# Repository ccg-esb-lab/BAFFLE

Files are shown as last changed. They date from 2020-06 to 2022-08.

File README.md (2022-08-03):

# BAFFLE - Bionic Apparatus For Fluorescent Light Estimation

Repository for: <br><br>
**BAFFLE: A 3D printable device for macroscopic quantification of fluorescent bacteria in space and time**<br>
_Carles Tardío Pi, Daniela Reyes-González, Andrea Fernández-Duque, Ayari Fuentes-Hernández, Fernando Santos-Escobar, and Rafael Peña-Miller_.


## Overview

Here you can find the hardware design files, code and materials for assemblying a low cost and open source opto-mechanical device with the aim of acquiring multi-channel time-lapse images of bacterial colonies growing in agar plates.  

This device uses a system of addressable LEDs and fluorescence filters to estimate the spatio-temporal distribution of different fluorescently-tagged sub-populations from time-lapse images obtained using a standard DSLR camera with a macro lens.

## Documentation

Step-by-step assembly instructions can be found [here](http://www.penamiller.com/lab/baffle/).<br>

List of components can be found [here](https://penamiller.com/lab/baffle/XLS/BAFFLEdoc_parts.xlsx).

Data used to produce figures included in the manuscript can be found in [data/](data/). 

ImageJ macros and Matlab scripts used to analyze these images can be found in [macros/](macros/).

## Authors

[@Systems Biology Lab, CCG-UNAM](https://github.com/ccg-esb-lab)

## License

[MIT](https://choosealicense.com/licenses/mit/)

This project is licensed under the MIT License - see the [license.txt](../license.txt) file for details. Hardware is lincesed under the CERN license.

## Aknowledgements

We thank the help and input from past and present members of the Systems and Synthetic Laboratory at CCG-UNAM.

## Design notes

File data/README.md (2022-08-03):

This directory contains raw images and data used to produce the figures in the manuscript "BAFFLE: A 3D printable device for macroscopic quantification of fluorescent bacteria in space and time".

*Figure 2* <br/>
Raw data: [data/Figure_calibration/](../data/Figure_calibration/)

*Figure 3* <br/>
Raw data: [data/Figure_colonies/](../data/Figure_colonies/)

*Figure 4* <br/>
Raw data: [data/Figure_gradient/](../data/Figure_gradient/)

*Figure 5* <br/>
Raw data: [data/Figure_timelapse/](../data/Figure_timelapse/)

*Figure 6* <br/>
Raw data: [data/Figure_expansion/](../data/Figure_expansion/)

## License

[MIT](https://choosealicense.com/licenses/mit/)

This project is licensed under the MIT License - see the [license.txt](../license.txt) file for details. Hardware is lincesed under the CERN license.

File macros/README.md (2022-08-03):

This directory contains [ImageJ](https://imagej.net/software/fiji/) macros used to process images used in the manuscript "BAFFLE: A 3D printable device for macroscopic quantification of fluorescent bacteria in space and time".

*Figure 2* <br/>
Macro: _Figure_calibration.ijm_ <br/>
Raw data: [data/Figure_calibration/](../data/Figure_calibration/)

*Figure 3* <br/>
Macro: _Figure_colonies.ijm_ <br/>
Raw data: [data/Figure_colonies/](../data/Figure_colonies/)

*Figure 4* <br/>
Raw data: [data/Figure_gradient/](../data/Figure_gradient/)

*Figure 5* <br/>
Macro: _Figure_timelapse.ijm_ <br/>
Raw data: [data/Figure_timelapse/](../data/Figure_timelapse/)

*Figure 6* <br/>
Macro: _Figure_expansion.ijm_ <br/>
Raw data: [data/Figure_expansion/](../data/Figure_expansion/)

Plots were generated in Matlab using the following script _runMe.m_

## License

[MIT](https://choosealicense.com/licenses/mit/)

This project is licensed under the MIT License - see the [license.txt](../license.txt) file for details. Hardware is lincesed under the CERN license.

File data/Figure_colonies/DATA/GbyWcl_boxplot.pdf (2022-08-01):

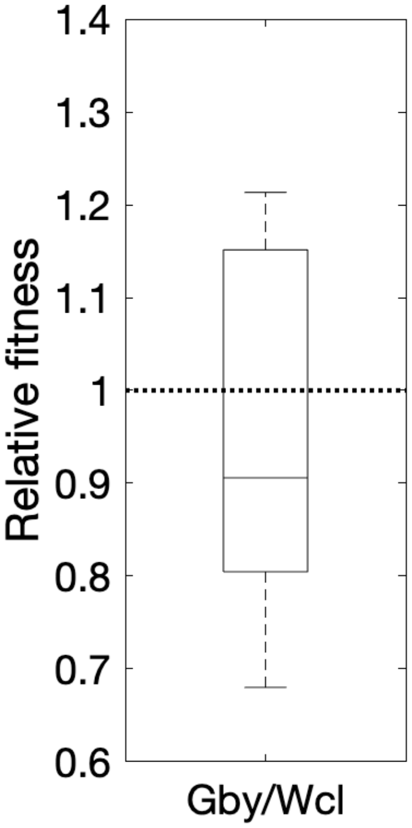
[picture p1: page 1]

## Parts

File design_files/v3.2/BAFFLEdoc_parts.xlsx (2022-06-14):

 | ELECTRONICS & PARTS LIST | REF | PRICE (APPROX. USD)
1 | PhidgetInterfaceKit 8/8/88 | https://www.phidgets.com/?prodid=1021 | 80$
2 | PhidgetStepper Bipolar HC | https://www.phidgets.com/?tier=3&catid=23&pcid=20&prodid=1029 | 180$
1 | Arduino Mega 2560 Rev3 | https://store.arduino.cc/products/arduino-mega-2560-rev3 | 33$
1 | Grove - Mega Shield v1.2 | https://www.seeedstudio.com/Grove-Mega-Shield-v1-2.html | 11$
1 | Grove - Temperature&Humidity Sensor | https://wiki.seeedstudio.com/Grove-TemptureAndHumidity_Sensor-High-Accuracy_AndMini-v1.0/ | 13$
2 | NEMA 17 Stepper Motor | https://openbuildspartstore.com/nema-17-stepper-motor/ | 36$
4 | SinkPAD-II 23mm Quad LED Modules | https://www.luxeonstar.com/sinkpad-23mm-quad-led-modules | 100$
4 | LED Heat Sink | https://www.luxeonstar.com/50mm-round-4.9-degree-cw-alpha-heat-sink | 33$
1 | BuckPuck DC LED Driver | https://www.luxeonstar.com/1000ma-externally-dimmable-buckpuck-dc-driver-leads | 11$
1 | 60leds/m 12v ws2812b led strip | https://www.alibaba.com/product-detail/12v-Led-Led-Waterproof-Led-Strip_62439538213.html?s=p | 25$
4 | Thorlabs Fluorescence Imaging Filters Kit | https://www.thorlabs.com/newgrouppage9.cfm?objectgroup_id=2990 | 1028$
3 | 5v Relay Module 1 Channel 12vdc | https://articulo.mercadolibre.com.mx/MLM-657067999-modulo-relevador-relay-1-canal-12v-_JM?matt_tool=54128181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 | 3$
5 | N-Channel MOSFET 60V 30A | https://www.sparkfun.com/products/10213 | 5$
1 | TEC1-12706 Peltier Kit | https://www.amazon.com.mx/Lsgoodcare-Semiconductor-Thermoel%C3%A9ctrico-refrigeraci%C3%B3n-TEC1-12706/dp/B09GFKWP49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 | 23$
1 | 12V 30A DC Regulated Power Supply | https://www.amazon.com.mx/BMOUO-Universal-Regulated-Switching-Computer/dp/B01EWG6YT8?adgrpid=101194324775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 | 40$
2 | Limit Switch | https://articulo.mercadolibre.com.mx/MLM-642073992-limit-switch-interruptor-final-carrera-kw11-3z-arduino-pic-_JM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 | 4$
4 | Thermal Adhesive Tape for 23 mm Quad LED Assemblies | https://www.luxeonstar.com/pre-cut-thermal-adhesive-tape-for-quad-leds-12pcs | 8$
1 | 2GT Timing Belt Pulley Kits GT2 Timing Belt Closed-Loop 200mm | https://www.amazon.com/dp/B01M2DL73S/ref=cm_sw_r_cp_api_i_Z3ENCbVTZ6J9D | 11$
4 | OpenBuilds V-Slot 20x20x200mm | https://openbuildspartstore.com/v-slot-20x20-linear-rail/ | 11$
6 | OpenBuilds V-Slot 20x20x250mm | https://openbuildspartstore.com/v-slot-20x20-linear-rail/ | 16$
4 | OpenBuilds V-Slot 20x20x500mm | https://openbuildspartstore.com/v-slot-20x20-linear-rail/ | 22$
5 | OpenBuilds V-Slot 20x40x500mm | https://openbuildspartstore.com/v-slot-20x40-linear-rail/ | 35$
2 | OpenBuilds V-Slot 20x40x250mm | https://openbuildspartstore.com/v-slot-20x40-linear-rail/ | 7$
1 | OpenBuilds V-Slot 40x40x500mm | https://openbuildspartstore.com/v-slot-40x40-linear-rail/ | 14$
16 | 90 Degree Joining Plate | https://openbuildspartstore.com/90-degree-joining-plate/ | 80$
24 | Inside Hidden Corner Bracket | https://openbuildspartstore.com/inside-hidden-corner-bracket/ | 47.76$
1 | OpenBuilds C-Beam Linear Rail | https://openbuildspartstore.com/c-beam-linear-rail/ | 18$
100 | Low Profile M5 Screw | https://openbuildspartstore.com/low-profile-screws-m5-10-pack/ | 9$
30 | Tee Nuts - M5 | https://openbuildspartstore.com/tee-nuts-m5-10-pack/ | 9$
12 | Drop In Tee Nuts | https://openbuildspartstore.com/drop-in-tee-nuts/ | 12$
2 | Motor Mount Plate - NEMA 17 Stepper Motor | https://openbuildspartstore.com/motor-mount-plate-nema-17-stepper-motor/ | 14$
2 | 1/4" x 8mm Flexible Coupling | https://openbuildspartstore.com/1-4-x-8mm-flexible-coupling/ | 14$
1 | 220Ω resistors | https://www.amazon.com/220-Ohm-Resistor/s?k=220+Ohm+Resistor | 6$
1 | 4N26 optocoupler | https://www.amazon.com/10PCS-4N26-OPTOCOUPLER-PHOTOTRANS-6DIP/dp/B01F16KRD2 | 6$
 | Acrylic sheets 3mm
 | Acrylic sheets 5mm
 | PLA filament
 | Canon Rebel T6i Body
 | Canon EF 100mm f/2.8 Macro USM Lens
 | PC with Ubuntu Linux
 |  |  | TOTAL (APPROX.)
 |  |  | 1671.76$

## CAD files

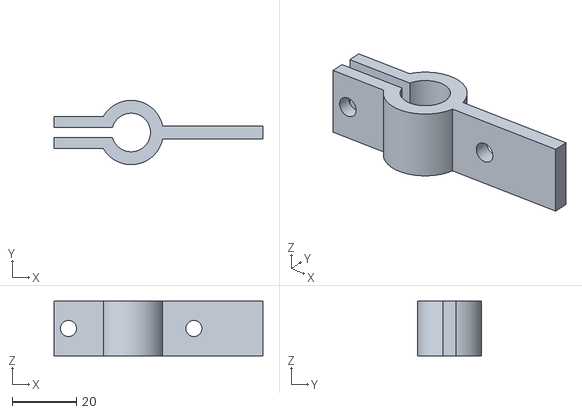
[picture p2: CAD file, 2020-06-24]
design_files/v3.2/STL/limitSwitch_holder.stl
65.0 x 20.0 x 17.0

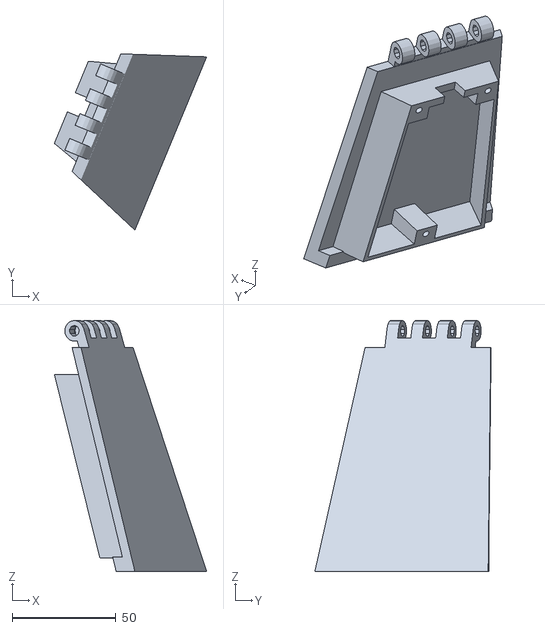
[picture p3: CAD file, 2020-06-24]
design_files/v3.2/STL/incubator_illuminator_ledsegment.stl
73.5 x 85.0 x 121.0

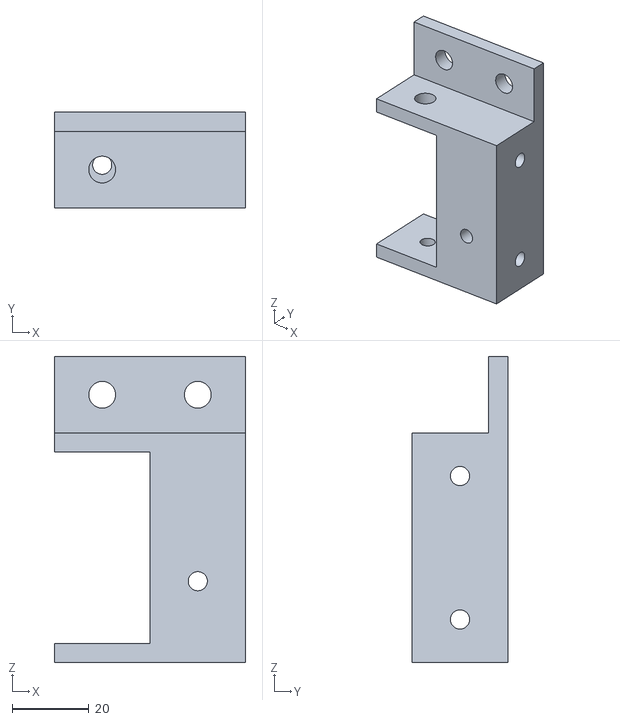
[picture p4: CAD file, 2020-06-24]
design_files/v3.2/STL/baffle_incubator_frontLeft.stl
50.0 x 25.0 x 80.0

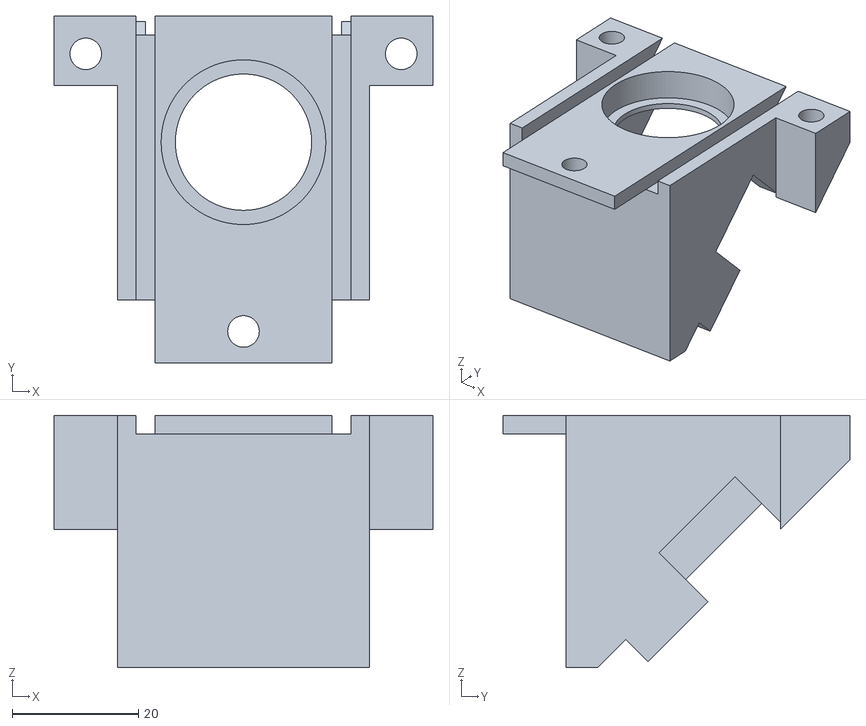
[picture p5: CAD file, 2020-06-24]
design_files/v3.2/STL/baffle_filterCube_top.stl
60.0 x 55.0 x 40.0

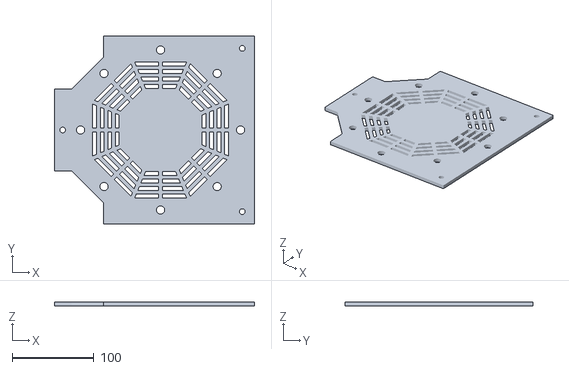
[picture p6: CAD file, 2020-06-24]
design_files/v3.2/STL/baffle_incubator_acrylic_top.stl
245.0 x 230.0 x 5.00

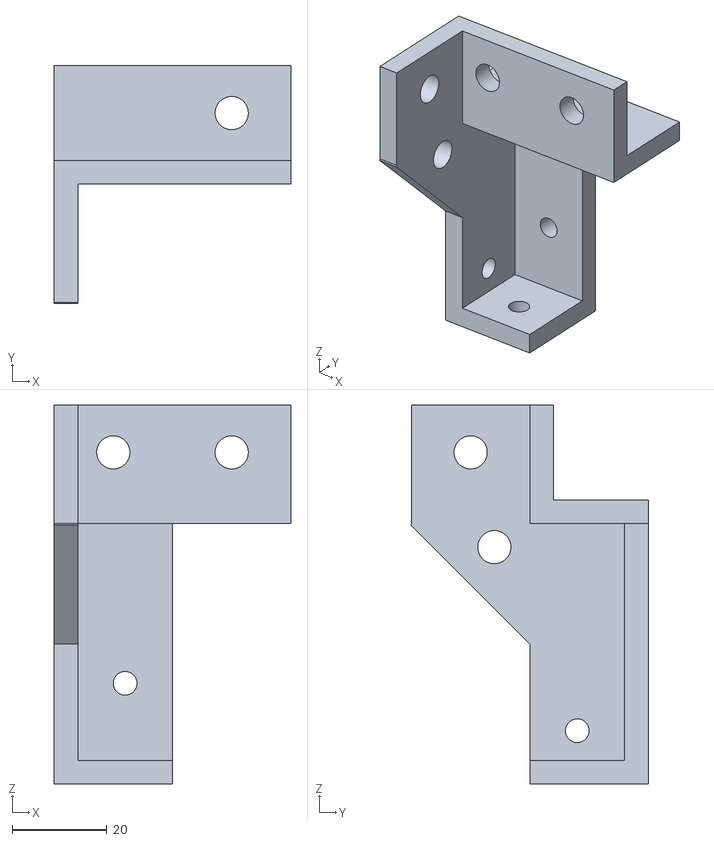
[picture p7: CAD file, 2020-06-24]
design_files/v3.2/STL/baffle_incubator_backRight.stl
50.0 x 50.2 x 80.0

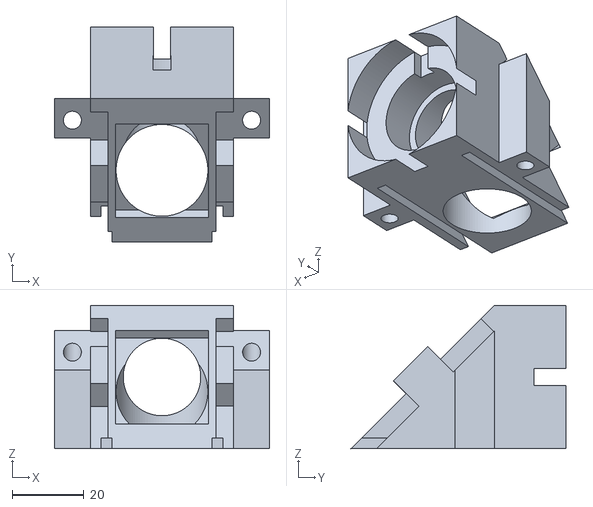
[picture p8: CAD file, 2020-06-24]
design_files/v3.2/STL/baffle_filterCube_bottom.stl
60.0 x 60.0 x 40.0

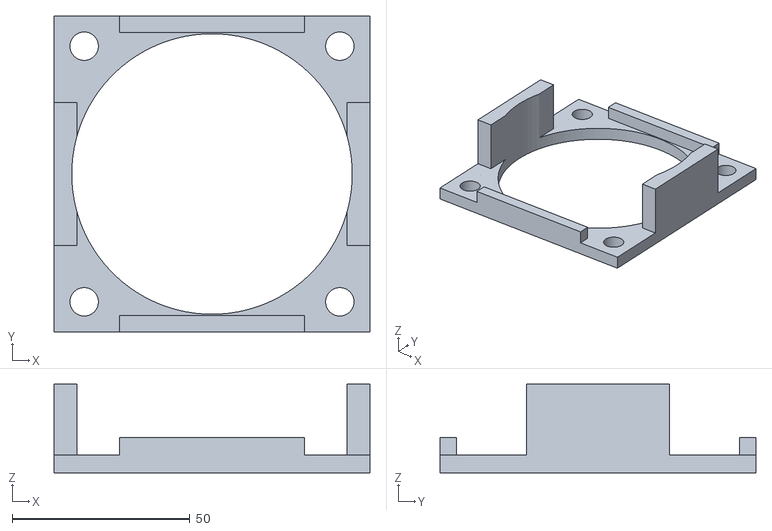
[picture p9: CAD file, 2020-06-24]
design_files/v3.2/STL/baffle_incubator_support.stl
89.0 x 89.0 x 25.0

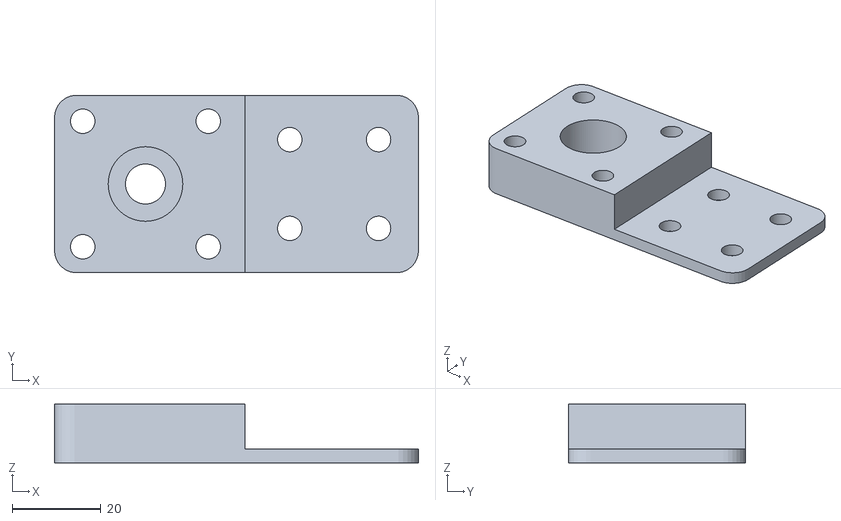
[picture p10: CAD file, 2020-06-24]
design_files/v3.2/STL/filter_wheel_shaft_top.stl
82.0 x 39.9 x 13.2

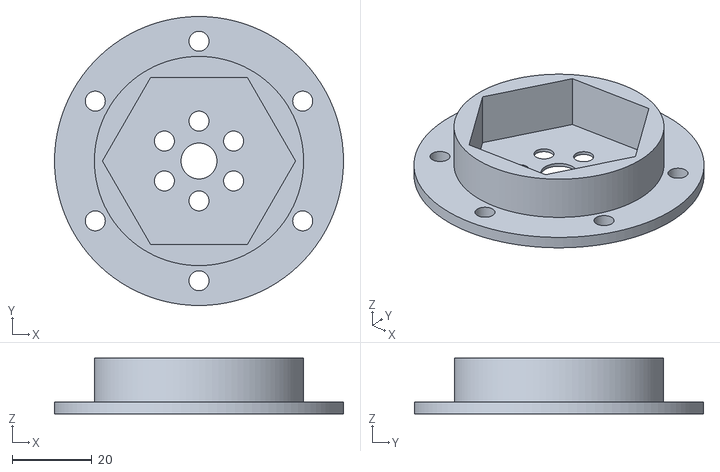
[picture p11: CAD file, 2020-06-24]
design_files/v3.2/STL/filter_wheel_support.stl
72.4 x 72.4 x 14.0

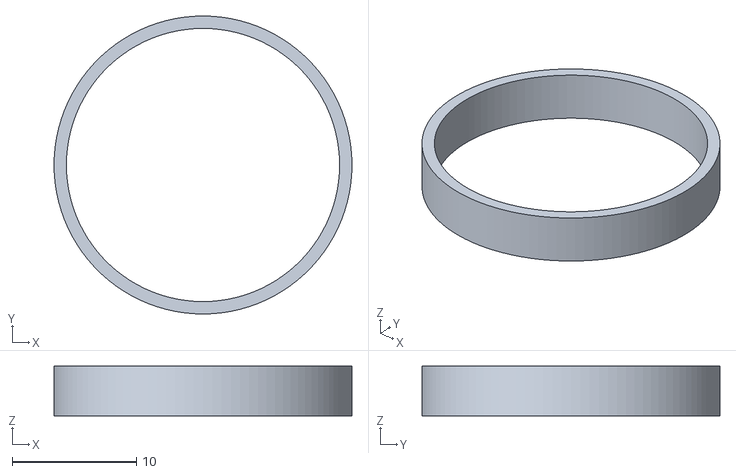
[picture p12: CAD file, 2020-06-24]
design_files/v3.2/STL/baffle_filterCube_spacer.stl
24.0 x 24.0 x 4.00

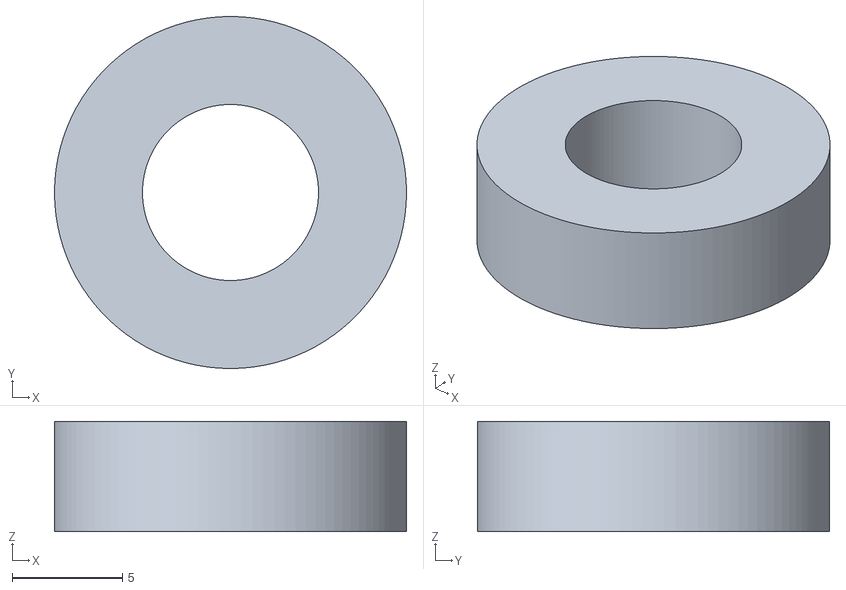
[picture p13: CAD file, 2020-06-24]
design_files/v3.2/STL/baffle_incubator_spacer.stl
16.0 x 16.0 x 5.00

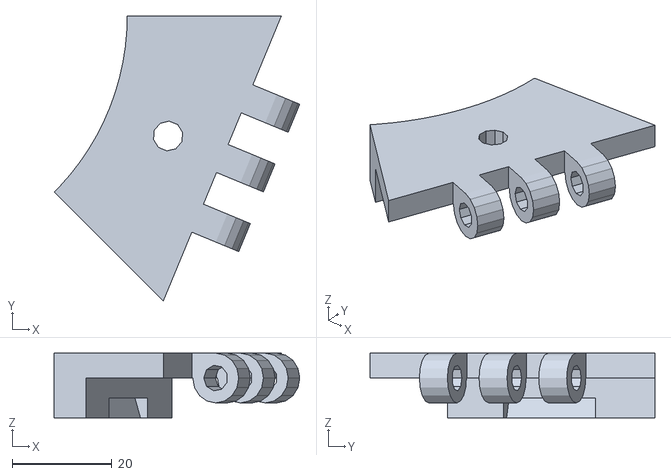
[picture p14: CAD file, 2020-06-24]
design_files/v3.2/STL/incubator_illuminator_hinge.stl
49.3 x 57.2 x 13.0

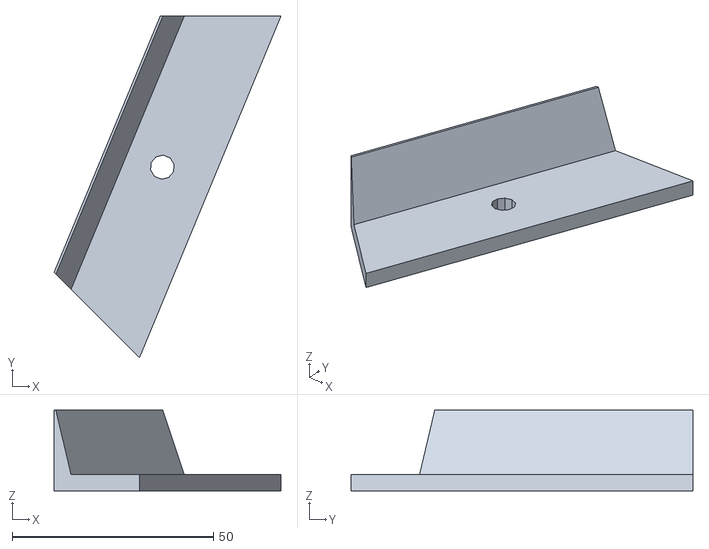
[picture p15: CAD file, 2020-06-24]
design_files/v3.2/STL/incubator_illuminator_base.stl
56.4 x 84.9 x 20.0

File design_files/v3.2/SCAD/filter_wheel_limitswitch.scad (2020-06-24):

intersection(){
#translate([15,10.1,-5]) cube([40,40,40], center=true);
rotate([45,0,0]) import("/Users/ESB/RPM_SYNC/RPM_Work/DIY/BAFFLE_v3.0/BAFFLE_dev/STL/2020_corner_single.stl");
}

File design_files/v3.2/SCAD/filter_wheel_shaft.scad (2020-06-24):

//import("/Users/ESB/Downloads/Motor_Mount_Plate.stl");

d=0.2;

wall=3;

$fs = 0.2;

w_plate=82;
h_plate=40;

depth_plate=3;

r_shaft=4.5;
r_bearing=8.4;

r_screw=2.75;

depth_device=20;

w_openbuilds=40;
depth_openbuilds=20;
l_openbuilds=100;

depth_bearing=6;

/********************/

//color([1,1,1]) translate([40+d,0,0]) cube([w_openbuilds, l_openbuilds, depth_openbuilds], center=true);

translate([0,0,-depth_device/2-d]) plate_top();

//translate([0,0,depth_device/2+d]) color([0,1,1]) mirror([0,0,1]) plate_top();

//color([1,0,1]) spacer();




module spacer(){
    difference() {
        translate([0,0,0]) cylinder(r=r_bearing-2*d, h=(depth_openbuilds)-2*depth_bearing-2*d, center=true, $fn=100);
        cylinder(r=r_shaft, h=depth_device*2, center=true, $fn=100);
        
    }
}


module plate_top(){

    //translate([w_plate/4,0,depth_openbuilds/4-depth_plate/2]) cube([w_plate, h_plate, depth_openbuilds/2+d+depth_plate], center=true);
    
    difference(){

        translate([w_plate/4,0,depth_openbuilds/4-depth_plate/2])  roundedcube([w_plate, h_plate, depth_openbuilds/2+d+depth_plate], true, 5, "z");
        
        translate([w_plate-w_openbuilds+.5,0,depth_openbuilds/2]) cube([w_openbuilds+d, h_plate+d, depth_openbuilds], center=true);
        
        cylinder(r=r_shaft, h=depth_device*2, center=true, $fn=100);
        translate([0,0,depth_openbuilds/2]) cylinder(r=r_bearing, h=depth_openbuilds, center=true, $fn=100);
        
        // Openbuilds Screws
        translate([32.5,10,0]) cylinder(r=r_screw, h=depth_device*2, center=true, $fn=100);
        translate([32.5,-10,0]) cylinder(r=r_screw, h=depth_device*2, center=true, $fn=100);
        translate([52.5,10,0]) cylinder(r=r_screw, h=depth_device*2, center=true, $fn=100);
        translate([52.5,-10,0]) cylinder(r=r_screw, h=depth_device*2, center=true, $fn=100);
        
        
        // Openbuilds Screws
        rotate([0,0,45]) translate([20,0,0]) cylinder(r=r_screw, h=depth_device*2, center=true, $fn=100);
        rotate([0,0,45*3]) translate([20,0,0]) cylinder(r=r_screw, h=depth_device*2, center=true, $fn=100);
        rotate([0,0,45*5]) translate([20,0,0]) cylinder(r=r_screw, h=depth_device*2, center=true, $fn=100);
        rotate([0,0,45*7]) translate([20,0,0]) cylinder(r=r_screw, h=depth_device*2, center=true, $fn=100);
    }
}



module roundedcube(size = [1, 1, 1], center = false, radius = 0.5, apply_to = "all") {
	// If single value, convert to [x, y, z] vector
	size = (size[0] == undef) ? [size, size, size] : size;

	translate_min = radius;
	translate_xmax = size[0] - radius;
	translate_ymax = size[1] - radius;
	translate_zmax = size[2] - radius;

	diameter = radius * 2;

	obj_translate = (center == false) ?
		[0, 0, 0] : [
			-(size[0] / 2),
			-(size[1] / 2),
			-(size[2] / 2)
		];

	translate(v = obj_translate) {
		hull() {
			for (translate_x = [translate_min, translate_xmax]) {
				x_at = (translate_x == translate_min) ? "min" : "max";
				for (translate_y = [translate_min, translate_ymax]) {
					y_at = (translate_y == translate_min) ? "min" : "max";
					for (translate_z = [translate_min, translate_zmax]) {
						z_at = (translate_z == translate_min) ? "min" : "max";

						translate(v = [translate_x, translate_y, translate_z])
						if (
							(apply_to == "all") ||
							(apply_to == "xmin" && x_at == "min") || (apply_to == "xmax" && x_at == "max") ||
							(apply_to == "ymin" && y_at == "min") || (apply_to == "ymax" && y_at == "max") ||
							(apply_to == "zmin" && z_at == "min") || (apply_to == "zmax" && z_at == "max")
						) {
							sphere(r = radius);
						} else {
							rotate = 
								(apply_to == "xmin" || apply_to == "xmax" || apply_to == "x") ? [0, 90, 0] : (
								(apply_to == "ymin" || apply_to == "ymax" || apply_to == "y") ? [90, 90, 0] :
								[0, 0, 0]
							);
							rotate(a = rotate)
							cylinder(h = diameter, r = radius, center = true);
						}
					}
				}
			}
		}
	}
}

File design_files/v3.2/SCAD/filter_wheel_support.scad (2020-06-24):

d=0.2;

r_shaft=4.5;

wall=3;

r_support=20+2*wall+d;

r_screw=2.5;

h_support=10+wall;

dist_screws=20;
r_bolt=r_screw+2;


r_disc=120;
r_camera=33;
dist_screws=20;
r_filter=12;

dist_filter_min=87.5;
dist_filter_max=98;

depth_acrylic1=5;
depth_acrylic2=3;

h_switch=30;
w_switch=5;
l_switch=60;

/********/


translate([0,0,h_support/2+3.1]) mirror([0,0,1]) support();


//limit_switch();

//projection(cut = false) 
//intersection(){
//color([0,0,0]) 


//projection(cut = false) 
color([1,.5,0]) disc1();



difference(){
    //translate([0,0,20])color([0,1,0])
    translate([0,0,5]) color([1,0,0])  
    //projection(cut = false) 
    disc2();
    translate([0,0,4.]) disc2_layer2();
}


//    rotate([0,0,-5]) translate([-125,-15,-5]) cube([250,30,10]);
//}

  translate([0,0,-0]) filter_cubes();


translate([0,0,-40-wall]) color([.5,1,0])   disc3();
//projection(cut = false)    
    

/***********************/

module filter_cubes(){
    color([1,0,1]){
        for (a =[0,60,180, 240]){
            rotate([0,0,a]) {
                translate([-20,30,-40]) import("../STL/baffle_filterCube_top.stl");
            }
        }
    }
        

    color([0,1,1]){
        for (a =[0,60,180, 240]){
            rotate([0,0,a])
                translate([-20,30,-40]) import("../STL/baffle_filterCube_bottom.stl");
        }   
    }
}

/*****************/

module disc2_layer2(){

        for (a =[0,60,180, 240]){
            rotate([0,0,a]) {
               // translate([-20,dist_filter-20,-40]) import("../STL/baffle_filterCube_top.stl");
            
                //Filter Screws
                translate([0,dist_filter_min-30,wall]) cylinder(r=r_bolt, h=h_support+d*2, $fn=100);
                translate([0,dist_filter_max-30,wall]) cylinder(r=r_bolt, h=h_support+d*2, $fn=100);
                translate([-r_bolt,dist_filter_min-30,wall]) cube([r_bolt*2, dist_filter_max-dist_filter_min, h_support+d*2]);
                
                
                translate([25,dist_filter_max+14,wall]) cylinder(r=r_bolt, h=h_support+d*2, $fn=100);
                translate([25,dist_filter_min+14,wall]) cylinder(r=r_bolt, h=h_support+d*2, $fn=100);
                translate([25-r_bolt,dist_filter_min+14,wall]) cube([r_bolt*2, dist_filter_max-dist_filter_min, h_support+d*2]);
                
                translate([-25,dist_filter_max+14,wall]) cylinder(r=r_bolt, h=h_support+d*2, $fn=100);
                translate([-25,dist_filter_min+14,wall]) cylinder(r=r_bolt, h=h_support+d*2, $fn=100);
                translate([-25-r_bolt,dist_filter_min+14,wall]) cube([r_bolt*2, dist_filter_max-dist_filter_min, h_support+d*2]);
        }
        //rotate([0,0,120]) translate([0,this_dist_filter-30,-50]) cylinder(r=r_screw, h=100, $fn=100);
        //rotate([0,0,300]) translate([0,dist_filter-30,-50]) cylinder(r=r_screw, h=100, $fn=100);
        
    }
      
        
        //Acrylic Screws (outer)
        for (a =[0,60,120,180, 240, 300]){
            rotate([0,0,a]) 
                rotate([0,0,30]) translate([0,r_disc-dist_screws,wall]) cylinder(r=r_bolt, h=h_support+d*2, $fn=6);
        }
        
     
        //Acrylic screws (cablebox)
        rotate([0,0,-240]) translate([0,r_disc-dist_screws,wall]) cylinder(r=r_bolt, h=h_support+d*2,  $fn=100);
        
        //Acrylic screws (limit switch)
        rotate([0,0,-220]) translate([0,r_disc-dist_screws,wall]) cylinder(r=r_bolt, h=h_support+d*2,  $fn=100);
        rotate([0,0,-260]) translate([0,r_disc-dist_screws,wall]) cylinder(r=r_bolt, h=h_support+d*2,  $fn=100);
        rotate([0,0,-220]) translate([0,r_disc-dist_screws*2,wall]) cylinder(r=r_bolt, h=h_support+d*2,  $fn=100);
        rotate([0,0,-260]) translate([0,r_disc-dist_screws*2,wall]) cylinder(r=r_bolt, h=h_support+d*2,  $fn=100);
        
        
        
}

module disc1(){

    
    difference(){
        cylinder(r=r_disc, h=depth_acrylic1, $fn=100);
        
        translate([0,0,-50]) cylinder(r=r_shaft, h=100, $fn=100);
        
        //Box cube holes
        for (a =[0,60,180, 240]){
            rotate([0,0,a]) {
                //translate([-20,dist_filter_min-60,-40]) import("../STL/baffle_filterCube_top.stl");
               // translate([-20,dist_filter_max-60,-40]) import("../STL/baffle_filterCube_top.stl");
                translate([-20-d*2,dist_filter_max-60-d*2+2,-10]) cube([40+d*4,80+d*4,20]);
                translate([-30-d*2,dist_filter_max-20-d*2,-10]) cube([10+d*4,40+d*4,20]);
                translate([20-d*2,dist_filter_max-20-d*2,-10]) cube([10+d*4,40+d*4,20]);
            
        }
        
    }
        
        //Center Screws
        for (a =[0,60,120,180, 240, 300]){
            rotate([0,0,a]) 
                translate([0,dist_screws/2,wall]) cylinder(r=r_screw, h=h_support+d*2, center=true, $fn=100);
        }
        
        //Acrylic Screws (inner)
        for (a =[0,60,120,180, 240, 300]){
            rotate([0,0,a]) 
                translate([0,dist_screws/2+dist_screws,wall]) cylinder(r=r_screw, h=h_support+d*2, center=true, $fn=100);
        }
        
        //Acrylic Screws (outer)
        for (a =[0,60,120,180, 240, 300]){
            rotate([0,0,a]) 
                rotate([0,0,30]) translate([0,r_disc-dist_screws,wall]) cylinder(r=r_screw, h=h_support+d*2, center=true, $fn=100);
        }
     
        //Acrylic screws (cablebox)
        rotate([0,0,-240]) translate([0,r_disc-dist_screws,wall]) cylinder(r=r_screw, h=h_support+d*2, center=true, $fn=100);
        
        //Acrylic screws (limit switch)
        rotate([0,0,-220]) translate([0,r_disc-dist_screws,wall]) cylinder(r=r_screw, h=h_support+d*2, center=true, $fn=100);
        rotate([0,0,-260]) translate([0,r_disc-dist_screws,wall]) cylinder(r=r_screw, h=h_support+d*2, center=true, $fn=100);
        rotate([0,0,-220]) translate([0,r_disc-dist_screws*2,wall]) cylinder(r=r_screw, h=h_support+d*2, center=true, $fn=100);
        rotate([0,0,-260]) translate([0,r_disc-dist_screws*2,wall]) cylinder(r=r_screw, h=h_support+d*2, center=true, $fn=100);
        
        //Camera hole
        rotate([0,0,300]) translate([0,dist_filter_min,wall]) cylinder(r=r_camera, h=h_support+d*2, center=true, $fn=100);
        rotate([0,0,300]) translate([0,dist_filter_max,wall]) cylinder(r=r_camera, h=h_support+d*2, center=true, $fn=100);
        rotate([0,0,300]) translate([-r_camera,dist_filter_min,-d]) cube([r_camera*2, dist_filter_max-dist_filter_min, h_support+d*2]);
        
        //Cable box
        w_cable_box=40;
        h_cable_box=40;
        rotate([0,0,-240]) translate([0,r_disc-dist_screws,wall]) cube([w_cable_box, h_cable_box, 10],center=true);
    }
}
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

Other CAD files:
design_files/v3.2/STL/baffle_incubator_backLeft.stl
design_files/v3.2/STL/filter_wheel_shaft_bottom.stl
design_files/v3.2/STL/filter_wheel_shaft_spacer.stl
design_files/v3.2/STL/baffle_incubator_frontRight.stl
design_files/v3.2/SCAD/baffle_illuminator.scad
design_files/v3.2/SCAD/baffle_incubator.scad
design_files/v3.2/SCAD/baffle_incubator_support.scad
design_files/v3.2/SCAD/baffle_transilluminator.scad
design_files/v3.2/SCAD/filterCube.scad
design_files/v3.2/SCAD/ito_plateLid.scad
design_files/v3.2/SCAD/limitSwitch_holder.scad
design_files/v3.2/STL/incubator_illuminator_support.stl
design_files/v3.2/SVG/baffle_transilluminator.scad

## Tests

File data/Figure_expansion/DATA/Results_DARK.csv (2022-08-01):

 | Label | Area | Mean | Min | Max | XM | YM | BX | BY | Width | Height | IntDen | RawIntDen | Slice
1 | RFP | 316 | 181.1646 | 159 | 197 | 1819.9958 | 1820.0000 | 1810 | 1810 | 20 | 20 | 57248.0000 | 57248.0000 | 1
2 | RFP | 948 | 181.4736 | 162 | 204 | 1819.8947 | 1819.9541 | 1800 | 1800 | 40 | 40 | 172037.0000 | 172037.0000 | 1
3 | RFP | 1564 | 181.6368 | 138 | 203 | 1819.6744 | 1819.9932 | 1790 | 1790 | 60 | 60 | 284080.0000 | 284080.0000 | 1
4 | RFP | 2196 | 183.7213 | 155 | 208 | 1819.5106 | 1820.0054 | 1780 | 1780 | 80 | 80 | 403452.0000 | 403452.0000 | 1
5 | RFP | 2836 | 184.4824 | 156 | 211 | 1819.5816 | 1820.0104 | 1770 | 1770 | 100 | 100 | 523192.0000 | 523192.0000 | 1
6 | RFP | 3444 | 186.7703 | 155 | 245 | 1819.1809 | 1820.0880 | 1760 | 1760 | 120 | 120 | 643237.0000 | 643237.0000 | 1
7 | RFP | 4076 | 187.3660 | 150 | 212 | 1819.1245 | 1820.1961 | 1750 | 1750 | 140 | 140 | 763704.0000 | 763704.0000 | 1
8 | RFP | 4728 | 189.2234 | 163 | 215 | 1818.9031 | 1820.5294 | 1740 | 1740 | 160 | 160 | 894648.0000 | 894648.0000 | 1
9 | RFP | 5340 | 190.5534 | 160 | 234 | 1818.7344 | 1820.8224 | 1730 | 1730 | 180 | 180 | 1017555.0000 | 1017555.0000 | 1
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

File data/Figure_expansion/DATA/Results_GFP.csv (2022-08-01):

 | Label | Area | Mean | Min | Max | XM | YM | BX | BY | Width | Height | IntDen | RawIntDen | Slice
1 | GFP | 316 | 38.5665 | 15 | 61 | 1819.9104 | 1820.0539 | 1810 | 1810 | 20 | 20 | 12187.0000 | 12187.0000 | 1
2 | GFP | 948 | 39.1129 | 9 | 75 | 1819.6068 | 1819.8908 | 1800 | 1800 | 40 | 40 | 37079.0000 | 37079.0000 | 1
3 | GFP | 1564 | 40.0627 | 8 | 74 | 1819.3970 | 1819.5662 | 1790 | 1790 | 60 | 60 | 62658.0000 | 62658.0000 | 1
4 | GFP | 2196 | 40.7468 | 6 | 84 | 1819.2763 | 1819.5652 | 1780 | 1780 | 80 | 80 | 89480.0000 | 89480.0000 | 1
5 | GFP | 2836 | 41.5913 | 10 | 84 | 1819.5928 | 1819.0543 | 1770 | 1770 | 100 | 100 | 117953.0000 | 117953.0000 | 1
6 | GFP | 3444 | 43.7468 | 11 | 142 | 1818.9713 | 1817.6447 | 1760 | 1760 | 120 | 120 | 150664.0000 | 150664.0000 | 1
7 | GFP | 4076 | 44.4507 | 8 | 83 | 1818.7947 | 1818.3176 | 1750 | 1750 | 140 | 140 | 181181.0000 | 181181.0000 | 1
8 | GFP | 4728 | 45.7811 | 8 | 86 | 1817.9738 | 1819.2098 | 1740 | 1740 | 160 | 160 | 216453.0000 | 216453.0000 | 1
9 | GFP | 5340 | 47.3082 | 8 | 90 | 1817.2931 | 1818.4315 | 1730 | 1730 | 180 | 180 | 252626.0000 | 252626.0000 | 1
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

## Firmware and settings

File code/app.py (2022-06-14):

import dash
from dash import dcc
from dash import html
import dash_bootstrap_components as dbc
from dash.dependencies import Input, Output, State
from dash import dash_table
import dash_daq as daq
import time
import sys
import re
from time import sleep

#Phidget specific imports (stepper22)
from Phidget22.Devices.DigitalInput import *
from Phidget22.Devices.DigitalOutput import *
from Phidget22.Devices.Stepper import *
from Phidget22.PhidgetException import *
from Phidget22.Phidget import *
from Phidget22.Devices.DigitalInput import DigitalInput

########################## Import libraries

CODE_path='./lib/'  
sys.path.insert(0, CODE_path)
from baffle import *

df_params=getParams()

########################## CSS STYLESHEETS

external_stylesheets = ['https://codepen.io/chriddyp/pen/bWLwgP.css']
app = dash.Dash(__name__, external_stylesheets=[dbc.themes.GRID])
app.css.config.serve_locally = False
app.css.append_css({'external_url': 'https://cdnjs.cloudflare.com/ajax/libs/font-awesome/4.7.0/css/font-awesome.min.css'})
theme = {
    'dark': True,
    'detail': '#77C3E5',
    'primary': '#77C3E5',
    'secondary': '#77C3E5'
}

########################## Container: I/O
body_IO = dbc.Container([

    #Power button
    daq.PowerButton(
        id='Z_STEPPER_engage',
        on=False,
        className='dark-theme-control',
        size=50
    ),
	dbc.Row([
        dbc.Col([
                html.P("Stepper (z-pos):"),
            ], className="col-7", style={"padding-left":10}),

        dbc.Col([
                dcc.Input(
                    id='z_stepper_serial',
                    size="7",
                    value=df_params.loc[1,'z_stepper_serial'],
                    placeholder=df_params.loc[1,'z_stepper_serial'],
                    style={'background-color':'#23262A','color':'#95999F'},
                ),
            ], className="col-3"),

        dbc.Col([
            daq.Indicator(
              id='z_stepper_engaged',
              value=False,
              style={"padding-left":10,"padding-top":5}
            ),
            ], className="col-2"),

    ],style={"margin-top":40}),

    dbc.Row([

        dbc.Col([
                html.P("Stepper (f_pos):"),
            ], className="col-7", style={"padding-left":10}),

        dbc.Col([
                dcc.Input(
                    id='f_stepper_serial',
                    size="7",
                    value=df_params.loc[1,'f_stepper_serial'],
                    placeholder=df_params.loc[1,'f_stepper_serial'],
                    style={'background-color':'#23262A','color':'#95999F'}
                ),
            ], className="col-3"),

        dbc.Col([
            daq.Indicator(
              id='f_stepper_engaged',
              value=False,
              style={"padding-left":10,"padding-top":5}
            ),
        ], className="col-2"),
    ],style={"padding-bottom":5}),


    
    dbc.Row([


        dbc.Col([
                html.P("InterfaceKit:"),
            ], className="col-7", style={"padding-left":10}),

        dbc.Col([

                dcc.Input(
                    id='interfaceKit_serial',
                    size="7",
                    value=df_params.loc[1,'interfaceKit_serial'],
                    placeholder=df_params.loc[1,'interfaceKit_serial'],
                    style={'background-color':'#23262A','color':'#95999F'},
                ),
            ], className="col-3"),

        dbc.Col([
            daq.Indicator(
              id='interfaceKit_engaged',
              value=False,
              style={"padding-left":10,"padding-top":5}
            ),
            ], className="col-2"),

            # Hidden div inside the app that stores the intermediate value
            html.Div(id='zpos_var', style={'display': 'none'}, children=([0])),
            html.Div(id='fpos_var', style={'display': 'none'}, children=([0])),

            html.Div(id='ledBRIGHT_isOn', style={'display': 'none'}, children=[0]),
            html.Div(id='ledDARK_isOn', style={'display': 'none'}, children=[0]),
            html.Div(id='ledGFP_isOn', style={'display': 'none'}, children=[0]),
            html.Div(id='ledCFP_isOn', style={'display': 'none'}, children=[0]),
            html.Div(id='ledRFP_isOn', style={'display': 'none'}, children=[0]),
            html.Div(id='ledYFP_isOn', style={'display': 'none'}, children=[0]),

            dcc.Interval(id="listener", interval=100, n_intervals=0),
            dcc.Interval(id="timelapse_t", interval=1000, n_intervals=0),



        ],style={"padding-bottom":5}),
    

    dbc.Row([

        dbc.Col([
                html.P("Arduino:"),
            ], className="col-7", style={"padding-left":10}),

        dbc.Col([
                dcc.Input(
                    id='arduino_usbport',
                    size="7",
                    value=df_params.loc[1,'arduino_usbport'],
                    placeholder=df_params.loc[1,'arduino_usbport'],
                    style={'background-color':'#23262A','color':'#95999F'}
                ),
            ], className="col-3"),

        dbc.Col([
            daq.Indicator(
              id='arduino_engaged',
              value=False,
              style={"padding-left":10,"padding-top":5}
            ),
        ], className="col-2"),
    ],style={"margin-bottom":20}),
    
	],style={"background-color":"#13161D","padding":10,"margin":0}, fluid=True),

    

########################## Container: STAGE

body_stage = dbc.Container([
	dbc.Row([
		dbc.Col([

			daq.Gauge(
				  id='fpos_gauge',
				  label='Filter Wheel',
				  labelPosition='top',
				  value=df_params.loc[1,'fpos_min']+(df_params.loc[1,'fpos_max']-df_params.loc[1,'fpos_min'])/2,
				  max=df_params.loc[1,'fpos_max'],
				  min=df_params.loc[1,'fpos_min'],
				  size=130
				),

		], width=3, style={"margin-left":10}),

		dbc.Col([
					html.Div(
						style={'width': '100%', 'display': 'inline-block','padding-left':20,'padding-right':20, 'padding-bottom':0,'padding-top':40},
						children=[
				    		html.Div(
									style={'width': '33%', 'padding':0,'float':'left'},
									children=[
								    	html.Button(id='btn-home', className='fa fa-home', style={"color":"#95999F"}),
				            ]),
							html.Div(
									style={'width': '33%', 'padding':0,'float':'left'},
									children=[
								    	html.Button(id='btn-up', className='fa fa-arrow-up', style={"color":"#95999F"}),
				            ]),
						]),

				    	html.Div(
							style={'width': '100%','padding-left':20,'padding-right':20,'float':'left'},
							children=[
								html.Div(style={'width': '33%', 'padding':0,'float':'left'},
								children=[
									html.Button(id='btn-plus', className='fa fa-arrow-left', style={"color":"#95999F"}),
								]),
								html.Div(
									style={'width': '33%', 'padding':0,'float':'left','color':'#000'},
									children=[
				                        html.Button(id='btn-click', className='fa fa-camera', style={"color":"#95999F"}),
                                    ]),

								html.Div(style={'width': '33%', 'padding':0,'float':'left','margin-left':2},
								children=[
									html.Button(id='btn-minus', className='fa fa-arrow-right', style={"color":"#95999F"}),
								]),
						]),

						html.Div(style={'width': '100%', 'display': 'inline-block','padding-left':20,'padding-right':20},
						children=[
							html.Div(style={'width': '33%', 'padding-top':10,'padding-left':10,'float':'left'},
									children=[
                                        daq.Slider(
                                            id='deltaJog_slider',
                                            marks={i: '{}'.format(10 ** i) for i in range(0,2)},
                                            size=50,
                                            min=0,
                                            max=2,
                                            value=1,
                                            step=0.005,
                                            updatemode='drag'
                                        ),

									]),

				    		html.Div(style={'width': '33%', 'padding':0,'float':'left','margin-top':8},
									children=[
								    	html.Button(id='btn-down', className='fa fa-arrow-down', style={"color":"#95999F"}),
									]),
						]),

		], width=5),

		dbc.Col([
				daq.Tank(
					id='zpos_tank',
					className='dark-theme-components',
					value=5000,
					#height=150,
					min=1,
					max=50000,
					label='Vertical Axis',
					labelPosition='top'
				),
		], width=3),
	],style={"background-color":"#13161D","padding":0,"padding-left":0,"padding-bottom":63}),
],fluid=True,
)

#################### Container: CONTROL
header_control=dbc.Container([
	dbc.Row([
		dbc.Col(["Control"
		],
		style={"margin-bottom":20,"padding":5})
	]),
],
)
body_control = dbc.Container([

	dbc.Row([
		dbc.Col([
			html.P("LED"),

		],width={"size": 2, "offset": 0}, style={"padding-left":20}),

		dbc.Col([
			html.P("Filter"),
		], className="col-3",style={"padding-left":20}),

		dbc.Col([
			html.P("Exposure",style={"padding-left":0}),
		], className="col-4"),

		dbc.Col([
			html.P("Set",style={"padding-left":0,"margin-left":10}),
		], className="col-1"),
	]),
    dbc.Row([
		dbc.Col([
			daq.BooleanSwitch(
			  id='ledBRIGHT_switch',
			  on=False
			)
		], width={"size": 2, "offset": 0} ,style={"padding-top":5,"margin-left":0}),

		dbc.Col([
			html.Button(id='btn-filterBRIGHT', children='BRIGHT',style={"color":"white","width":100,"margin-right":0}),
		], className="col-3"),

		dbc.Col([
			daq.Slider(
				id='filterBRIGHT_slider',
				#marks={i: '{}'.format(10 ** i) for i in range(-2,2)},
				size=100,
				min=-3,
		       max=1,
		       value=0.001,
		       step=0.0005,
		       updatemode='drag'
			),
		], className="col-3",style={"padding-top":10}),
		dbc.Col([
			html.Div(id='exposureBRIGHT',style={"padding-top":5})
		], className="col-1"),
		dbc.Col([

			html.Button(id='btn-set-BRIGHT', className='fa fa-angle-double-left',
				style={"width":20,"padding":0, "margin-right":0, "height":20,"margin-top":3,"color":"#95999F"}),

		], className="col-2",style={"padding-top":5,"margin-left":10}),
	]),
	dbc.Row([
		dbc.Col([
			daq.BooleanSwitch(
			  id='ledDARK_switch',
			  on=False
			)
		], width={"size": 2, "offset": 0} ,style={"padding-top":5,"margin-left":0}),

		dbc.Col([
			html.Button(id='btn-filterDARK', children='DARK',style={"color":"DARK","width":100,"margin-right":0}),
		], className="col-3"),

		dbc.Col([
			daq.Slider(
				id='filterDARK_slider',
				#marks={i: '{}'.format(10 ** i) for i in range(-2,2)},
				size=100,
				min=-3,
		       max=1,
		       value=0.001,
		       step=0.005,
		       updatemode='drag'
			),
		], className="col-3",style={"padding-top":10}),
		dbc.Col([
			html.Div(id='exposureDARK',style={"padding-top":5})
		], className="col-1"),
		dbc.Col([

			html.Button(id='btn-set-DARK', className='fa fa-angle-double-left',
				style={"width":20,"padding":0, "margin-right":0, "height":20,"margin-top":3,"color":"#95999F"}),

		], className="col-2",style={"padding-top":5,"margin-left":10}),
	]),
	dbc.Row([
		dbc.Col([
			daq.BooleanSwitch(
			  id='ledGFP_switch',
			  on=False
			)
		], className="col-2",style={"padding-top":5}),

		dbc.Col([
			  	html.Button(id='btn-filterGFP', children='GFP',style={"color":"#C2E8B8","width":100}),
		], className="col-3"),

		dbc.Col([
			daq.Slider(
				id='filterGFP_slider',
				#marks={i: '{}'.format(10 ** i) for i in range(-2,2)},
				size=100,
				min=-3,
		       max=1,
		       value=0.001,
		       step=0.005,
		       updatemode='drag',
			),
		], className="col-3",style={"padding-top":10}),

		dbc.Col([
			html.Div(id='exposureGFP')
		], className="col-1",style={"padding-top":5}),

		dbc.Col([

			html.Button(id='btn-set-GFP', className='fa fa-angle-double-left',
				style={"width":20,"padding":0, "margin":0, "height":20,"margin-top":3,"color":"#95999F"}),

		], className="col-1",style={"padding-top":5,"margin-left":10}),
	]),

	dbc.Row([
		dbc.Col([
			daq.BooleanSwitch(
			  id='ledRFP_switch',
			  on=False
			)
		], className="col-2",style={"padding-top":5}),

		dbc.Col([
			html.Button(id='btn-filterRFP', children='RFP',style={"color":"#F8A39D","width":100}),
		], className="col-3"),

		dbc.Col([
			daq.Slider(
				id='filterRFP_slider',
				#marks={i: '{}'.format(10 ** i) for i in range(-2,2)},
				size=100,
				min=-3,
		       max=1,
		       value=0.001,
		        step=0.005,
		        updatemode='drag'
			),
		], className="col-3",style={"padding-top":10}),
		dbc.Col([
			html.Div(id='exposureRFP'),


		], className="col-1",style={"padding-top":5}),

		dbc.Col([

			html.Button(id='btn-set-RFP', className='fa fa-angle-double-left',
				style={"width":20,"padding":0, "margin":0, "height":20,"margin-top":3,"color":"#95999F"}),

		], className="col-1",style={"padding-top":5,"margin-left":10}),
	]),

	dbc.Row([
		dbc.Col([
			daq.BooleanSwitch(
			  id='ledCFP_switch',
			  on=False
			)
		], className="col-2",style={"padding-top":5}),

		dbc.Col([
			html.Button(id='btn-filterCFP', children='CFP',style={"color":"#A5C1DB","width":100}),
		], className="col-3"),

		dbc.Col([
			daq.Slider(
				id='filterCFP_slider',
				#marks={i: '{}'.format(10 ** i) for i in range(-2,2)},
				size=100,
				min=-3,
		       max=1,
		       value=0.001,
		       step=0.005,
		       updatemode='drag'
			),
		], className="col-3",style={"padding-top":10}),

		dbc.Col([
			html.Div(id='exposureCFP')
		], className="col-1",style={"padding-top":5}),
		dbc.Col([

			html.Button(id='btn-set-CFP', className='fa fa-angle-double-left',
				style={"width":20,"padding":0, "margin":0, "height":20,"margin-top":3,"color":"#95999F"}),

		], className="col-1",style={"padding-top":5,"margin-left":10}),
	]),

	dbc.Row([
		dbc.Col([
			daq.BooleanSwitch(
			  id='ledYFP_switch',
			  on=False
			)
		], width={"size": 2, "offset": 0},style={"padding-top":5}),

		dbc.Col([
			html.Button(id='btn-filterYFP', children='YFP',style={"color":"#FFFFA4","width":100}),
		], className="col-3", style={"float":"center"}),

		dbc.Col([
			daq.Slider(
				id='filterYFP_slider',
				#marks={i: '{}'.format(10 ** i) for i in range(-2,2)},
				size=100,
				min=-3,
		       max=1,
		       value=0.001,
		       step=0.005,
		       updatemode='drag'
			),
		], className="col-3",style={"padding-top":10}),
		dbc.Col([
			html.Div(id='exposureYFP')
		], className="col-1",style={"padding-top":5}),
		dbc.Col([

			html.Button(id='btn-set-YFP', className='fa fa-angle-double-left',
				style={"width":20,"padding":0, "margin":0, "height":20,"margin-top":3,"color":"#95999F"}),

		], className="col-1",style={"padding-top":5,"margin-left":10}),
	]),
],style={"background-color":"#13161D","padding":10,"margin-top":0,"padding-left":30}, fluid=True)

#################### CONTROL
body_timelapse = dbc.Container([

     dbc.Row([


        dbc.Col([

            html.Div([
                dcc.Interval(
                    id='interval_temperature',
                    interval=500, # in milliseconds
                    n_intervals=0
                )
            ]),

            dbc.Row([
                dbc.Col([
                  daq.LEDDisplay(
                        id='current_temperature',
                        value="0.0"
                    ),



				], className="col-8"),

                dbc.Col([
                    html.Div([

                        html.P("Heating "),
                        daq.Indicator(
                          id='incubator_on',
                          color="#00cc96",
                          value=False
                        ),


                        daq.Slider(
                            id='target_temperature',
                            min=21, max=42, value=30,
                            handleLabel={"showCurrentValue": True,"label": "target"},
                            step=1,
                            marks={'30': '30C', '37': '37C'}
                        ),

                    ]),

				], className="col-4"),

			]),
            
            html.Div([
                dcc.Interval(
                    id='interval_humidity',
                    interval=500, # in milliseconds
                    n_intervals=0
                )
            ]),
            
              dbc.Row([
                dbc.Col([
                  daq.LEDDisplay(
                        id='current_humidity',
                        value="0.0"
                    ),



				], className="col-8"),

                dbc.Col([
                    html.Div([

                        html.P("Humidity "),
                        daq.Indicator(
                          id='humidity_on',
                          color="#00cc96",
                          value=False
                        ),


                        daq.Slider(
                            id='target_humidity',
                            min=0, max=100, value=50,
                            handleLabel={"showCurrentValue": True,"label": "target"},
                            step=1,
                            marks={'0': '0%', '50': '50%', '100': '100%'}
                        ),

                    ]),

				], className="col-4"),

			]),




        ], className="col-6"),




			]),

	dbc.Row([
		dbc.Col([
			dbc.Row([

				dbc.Col([
					dcc.Checklist(
						id='incubator_checkbox',
					    options=[
					        {'label': ' Incubate', 'value': 'heatON'},
					    ],
					    style={"padding-left":15,"font-size":12,"display":"none"},
					    value=[]
					)
				], className="col-12"),

			]),
            dbc.Row([

				dbc.Col([
					dcc.Checklist(
						id='humidity_checkbox',
					    options=[
					        {'label': ' Humidity', 'value': 'humidityON'},
					    ],
					    style={"padding-left":15,"font-size":12,"display":"none"},
					    value=[]
					)
				], className="col-12"),

			]),


		], width={"size": 6, "offset": 0}),




	],style={"margin-bottom":0,"margin-top":10}),

],style={"background-color":"#13161D","padding":10,"margin-top":0}, fluid=True
)


body_buttons = dbc.Container([


    dbc.Row([

				dbc.Col([
					html.P("Interval (seconds):", style={"padding-left":15,"text-align":"right"}),
				], className="col-9"),

				dbc.Col([
                    dcc.Input(
								id='cycles_input',
								size="6",
                                value=1000,
                                style={'display': 'none'},
							),

					dcc.Input(
						id='interval_input',
						size="6",
                        value='600',
				  		style={'background-color':'#23262A','color':'#95999F',"text-align":"right",'margin-right':'20px'}
					),
				], className="col-3"),

			]),


	dbc.Row([
			dbc.Col([

                #TABLE
                html.Div([

                    dash_table.DataTable(
                        id='tbl_opt_config',
                        columns=[{
                            'name': 'Optical Configurations',
                            'id': 'opt_config-{}'.format(i),
                            'deletable': True,
                            'renamable': True
                        } for i in range(1, 2)],
                        data=[
                        ],
                        style_as_list_view=True,
                        style_cell={
                            'padding': '5px',
                            'backgroundColor': '#13161D',
                            'font-size':12,
                        },
                        style_header={
                            'backgroundColor': '#13161D',
                        },
                        editable=False,
                        row_deletable=True
                    ),



                ]),

                html.Button('Add', id='add_config-button',style={"width":100}, n_clicks=0),
				html.Button(id='btn-runOne', children='Run 1',style={"width":100}),
				html.Button(id='btn-runtimelapse', children='Loop',style={"width":100}),
				html.Button(id='btn-stop', children='Stop',style={"width":100}),

				html.P("Progress:",style={"margin-top":10}),

				daq.GraduatedBar(
					id='ncycles_progressbar',
					value=4
				),
                html.Div(
				    id='runtimelapse_output',
					style={"padding":0,"margin":0,"font-size":10},
                ),

                


			],
			style={"margin-bottom":20,"padding":15,"margin-top":0}, className="col-12"),
		
        
         dbc.Col([

                html.P("Time before next cycle:", style={"padding-top":30}),
					daq.LEDDisplay(
					id='timer_display',
					value="00:10"
				),
        ], className="col-9"),
    
    ]),


],style={"background-color":"#13161D","padding":10,"margin-top":0}, fluid=True,)
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

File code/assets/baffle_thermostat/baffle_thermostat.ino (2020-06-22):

/*
    Demo name   : TH02_dev demo
    Usage       : DIGITAL I2C HUMIDITY AND TEMPERATURE SENSOR
    Author      : Oliver Wang from Seeed Studio
    Version     : V0.1
*/

#include <TH02_dev.h>
#include "Arduino.h"
#include "Wire.h"

void setup() {
    Serial.begin(9600);        // start serial for output
    /* Power up,delay 150ms,until voltage is stable */
    delay(150);
    /* Reset HP20x_dev */
    TH02.begin();
    delay(100);
}


void loop() {
    float temper = TH02.ReadTemperature();
    //Serial.println("Temperature: ");
    Serial.print(temper);
    Serial.print("/");

    float humidity = TH02.ReadHumidity();
    Serial.print(humidity);
    Serial.println("\r");
    delay(1000);
}

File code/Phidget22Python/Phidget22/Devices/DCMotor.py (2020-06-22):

import sys
import ctypes
from Phidget22.PhidgetSupport import PhidgetSupport
from Phidget22.Async import *
from Phidget22.FanMode import FanMode
from Phidget22.PhidgetException import PhidgetException

from Phidget22.Phidget import Phidget

class DCMotor(Phidget):

	def __init__(self):
		Phidget.__init__(self)
		self.handle = ctypes.c_void_p()

		if sys.platform == 'win32':
			self._BackEMFChangeFactory = ctypes.WINFUNCTYPE(None, ctypes.c_void_p, ctypes.c_void_p, ctypes.c_double)
		else:
			self._BackEMFChangeFactory = ctypes.CFUNCTYPE(None, ctypes.c_void_p, ctypes.c_void_p, ctypes.c_double)
		self._BackEMFChange = None
		self._onBackEMFChange = None

		if sys.platform == 'win32':
			self._BrakingStrengthChangeFactory = ctypes.WINFUNCTYPE(None, ctypes.c_void_p, ctypes.c_void_p, ctypes.c_double)
		else:
			self._BrakingStrengthChangeFactory = ctypes.CFUNCTYPE(None, ctypes.c_void_p, ctypes.c_void_p, ctypes.c_double)
		self._BrakingStrengthChange = None
		self._onBrakingStrengthChange = None

		if sys.platform == 'win32':
			self._VelocityUpdateFactory = ctypes.WINFUNCTYPE(None, ctypes.c_void_p, ctypes.c_void_p, ctypes.c_double)
		else:
			self._VelocityUpdateFactory = ctypes.CFUNCTYPE(None, ctypes.c_void_p, ctypes.c_void_p, ctypes.c_double)
		self._VelocityUpdate = None
		self._onVelocityUpdate = None

		__func = PhidgetSupport.getDll().PhidgetDCMotor_create
		__func.restype = ctypes.c_int32
		res = __func(ctypes.byref(self.handle))

		if res > 0:
			raise PhidgetException(res)

	def __del__(self):
		Phidget.__del__(self)

	def _localBackEMFChangeEvent(self, handle, userPtr, backEMF):
		if self._BackEMFChange == None:
			return
		self._BackEMFChange(self, backEMF)

	def setOnBackEMFChangeHandler(self, handler):
		if handler == None:
			self._BackEMFChange = None
			self._onBackEMFChange = None
		else:
			self._BackEMFChange = handler
			self._onBackEMFChange = self._BackEMFChangeFactory(self._localBackEMFChangeEvent)

		try:
			__func = PhidgetSupport.getDll().PhidgetDCMotor_setOnBackEMFChangeHandler
			__func.restype = ctypes.c_int32
			res = __func(self.handle, self._onBackEMFChange, None)
		except RuntimeError:
			self._BackEMFChange = None
			self._onBackEMFChange = None

	def _localBrakingStrengthChangeEvent(self, handle, userPtr, brakingStrength):
		if self._BrakingStrengthChange == None:
			return
		self._BrakingStrengthChange(self, brakingStrength)

	def setOnBrakingStrengthChangeHandler(self, handler):
		if handler == None:
			self._BrakingStrengthChange = None
			self._onBrakingStrengthChange = None
		else:
			self._BrakingStrengthChange = handler
			self._onBrakingStrengthChange = self._BrakingStrengthChangeFactory(self._localBrakingStrengthChangeEvent)

		try:
			__func = PhidgetSupport.getDll().PhidgetDCMotor_setOnBrakingStrengthChangeHandler
			__func.restype = ctypes.c_int32
			res = __func(self.handle, self._onBrakingStrengthChange, None)
		except RuntimeError:
			self._BrakingStrengthChange = None
			self._onBrakingStrengthChange = None

	def _localVelocityUpdateEvent(self, handle, userPtr, velocity):
		if self._VelocityUpdate == None:
			return
		self._VelocityUpdate(self, velocity)

	def setOnVelocityUpdateHandler(self, handler):
		if handler == None:
			self._VelocityUpdate = None
			self._onVelocityUpdate = None
		else:
			self._VelocityUpdate = handler
			self._onVelocityUpdate = self._VelocityUpdateFactory(self._localVelocityUpdateEvent)

		try:
			__func = PhidgetSupport.getDll().PhidgetDCMotor_setOnVelocityUpdateHandler
			__func.restype = ctypes.c_int32
			res = __func(self.handle, self._onVelocityUpdate, None)
		except RuntimeError:
			self._VelocityUpdate = None
			self._onVelocityUpdate = None

	def getAcceleration(self):
		_Acceleration = ctypes.c_double()

		__func = PhidgetSupport.getDll().PhidgetDCMotor_getAcceleration
		__func.restype = ctypes.c_int32
		result = __func(self.handle, ctypes.byref(_Acceleration))

		if result > 0:
			raise PhidgetException(result)

		return _Acceleration.value

	def setAcceleration(self, Acceleration):
		_Acceleration = ctypes.c_double(Acceleration)

		__func = PhidgetSupport.getDll().PhidgetDCMotor_setAcceleration
		__func.restype = ctypes.c_int32
		result = __func(self.handle, _Acceleration)

		if result > 0:
			raise PhidgetException(result)


	def getMinAcceleration(self):
		_MinAcceleration = ctypes.c_double()

		__func = PhidgetSupport.getDll().PhidgetDCMotor_getMinAcceleration
		__func.restype = ctypes.c_int32
		result = __func(self.handle, ctypes.byref(_MinAcceleration))

		if result > 0:
			raise PhidgetException(result)

		return _MinAcceleration.value

	def getMaxAcceleration(self):
		_MaxAcceleration = ctypes.c_double()

		__func = PhidgetSupport.getDll().PhidgetDCMotor_getMaxAcceleration
		__func.restype = ctypes.c_int32
		result = __func(self.handle, ctypes.byref(_MaxAcceleration))

		if result > 0:
			raise PhidgetException(result)

		return _MaxAcceleration.value

	def getBackEMF(self):
		_BackEMF = ctypes.c_double()

		__func = PhidgetSupport.getDll().PhidgetDCMotor_getBackEMF
		__func.restype = ctypes.c_int32
		result = __func(self.handle, ctypes.byref(_BackEMF))

		if result > 0:
			raise PhidgetException(result)

		return _BackEMF.value

	def getBackEMFSensingState(self):
		_BackEMFSensingState = ctypes.c_int()

		__func = PhidgetSupport.getDll().PhidgetDCMotor_getBackEMFSensingState
		__func.restype = ctypes.c_int32
		result = __func(self.handle, ctypes.byref(_BackEMFSensingState))

		if result > 0:
			raise PhidgetException(result)

		return _BackEMFSensingState.value

	def setBackEMFSensingState(self, BackEMFSensingState):
		_BackEMFSensingState = ctypes.c_int(BackEMFSensingState)

		__func = PhidgetSupport.getDll().PhidgetDCMotor_setBackEMFSensingState
		__func.restype = ctypes.c_int32
		result = __func(self.handle, _BackEMFSensingState)

		if result > 0:
			raise PhidgetException(result)


	def getBrakingStrength(self):
		_BrakingStrength = ctypes.c_double()

		__func = PhidgetSupport.getDll().PhidgetDCMotor_getBrakingStrength
		__func.restype = ctypes.c_int32
		result = __func(self.handle, ctypes.byref(_BrakingStrength))

		if result > 0:
			raise PhidgetException(result)

		return _BrakingStrength.value

	def getMinBrakingStrength(self):
		_MinBrakingStrength = ctypes.c_double()

		__func = PhidgetSupport.getDll().PhidgetDCMotor_getMinBrakingStrength
		__func.restype = ctypes.c_int32
		result = __func(self.handle, ctypes.byref(_MinBrakingStrength))

		if result > 0:
			raise PhidgetException(result)

		return _MinBrakingStrength.value

	def getMaxBrakingStrength(self):
		_MaxBrakingStrength = ctypes.c_double()

		__func = PhidgetSupport.getDll().PhidgetDCMotor_getMaxBrakingStrength
		__func.restype = ctypes.c_int32
		result = __func(self.handle, ctypes.byref(_MaxBrakingStrength))

		if result > 0:
			raise PhidgetException(result)

		return _MaxBrakingStrength.value

	def getCurrentLimit(self):
		_CurrentLimit = ctypes.c_double()
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

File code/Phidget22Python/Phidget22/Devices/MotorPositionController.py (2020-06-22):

import sys
import ctypes
from Phidget22.PhidgetSupport import PhidgetSupport
from Phidget22.Async import *
from Phidget22.FanMode import FanMode
from Phidget22.EncoderIOMode import EncoderIOMode
from Phidget22.PhidgetException import PhidgetException

from Phidget22.Phidget import Phidget

class MotorPositionController(Phidget):

	def __init__(self):
		Phidget.__init__(self)
		self.handle = ctypes.c_void_p()
		self._setTargetPosition_async = None
		self._onsetTargetPosition_async = None

		if sys.platform == 'win32':
			self._DutyCycleUpdateFactory = ctypes.WINFUNCTYPE(None, ctypes.c_void_p, ctypes.c_void_p, ctypes.c_double)
		else:
			self._DutyCycleUpdateFactory = ctypes.CFUNCTYPE(None, ctypes.c_void_p, ctypes.c_void_p, ctypes.c_double)
		self._DutyCycleUpdate = None
		self._onDutyCycleUpdate = None

		if sys.platform == 'win32':
			self._PositionChangeFactory = ctypes.WINFUNCTYPE(None, ctypes.c_void_p, ctypes.c_void_p, ctypes.c_double)
		else:
			self._PositionChangeFactory = ctypes.CFUNCTYPE(None, ctypes.c_void_p, ctypes.c_void_p, ctypes.c_double)
		self._PositionChange = None
		self._onPositionChange = None

		__func = PhidgetSupport.getDll().PhidgetMotorPositionController_create
		__func.restype = ctypes.c_int32
		res = __func(ctypes.byref(self.handle))

		if res > 0:
			raise PhidgetException(res)

	def __del__(self):
		Phidget.__del__(self)

	def _localDutyCycleUpdateEvent(self, handle, userPtr, dutyCycle):
		if self._DutyCycleUpdate == None:
			return
		self._DutyCycleUpdate(self, dutyCycle)

	def setOnDutyCycleUpdateHandler(self, handler):
		if handler == None:
			self._DutyCycleUpdate = None
			self._onDutyCycleUpdate = None
		else:
			self._DutyCycleUpdate = handler
			self._onDutyCycleUpdate = self._DutyCycleUpdateFactory(self._localDutyCycleUpdateEvent)

		try:
			__func = PhidgetSupport.getDll().PhidgetMotorPositionController_setOnDutyCycleUpdateHandler
			__func.restype = ctypes.c_int32
			res = __func(self.handle, self._onDutyCycleUpdate, None)
		except RuntimeError:
			self._DutyCycleUpdate = None
			self._onDutyCycleUpdate = None

	def _localPositionChangeEvent(self, handle, userPtr, position):
		if self._PositionChange == None:
			return
		self._PositionChange(self, position)

	def setOnPositionChangeHandler(self, handler):
		if handler == None:
			self._PositionChange = None
			self._onPositionChange = None
		else:
			self._PositionChange = handler
			self._onPositionChange = self._PositionChangeFactory(self._localPositionChangeEvent)

		try:
			__func = PhidgetSupport.getDll().PhidgetMotorPositionController_setOnPositionChangeHandler
			__func.restype = ctypes.c_int32
			res = __func(self.handle, self._onPositionChange, None)
		except RuntimeError:
			self._PositionChange = None
			self._onPositionChange = None

	def getAcceleration(self):
		_Acceleration = ctypes.c_double()

		__func = PhidgetSupport.getDll().PhidgetMotorPositionController_getAcceleration
		__func.restype = ctypes.c_int32
		result = __func(self.handle, ctypes.byref(_Acceleration))

		if result > 0:
			raise PhidgetException(result)

		return _Acceleration.value

	def setAcceleration(self, Acceleration):
		_Acceleration = ctypes.c_double(Acceleration)

		__func = PhidgetSupport.getDll().PhidgetMotorPositionController_setAcceleration
		__func.restype = ctypes.c_int32
		result = __func(self.handle, _Acceleration)

		if result > 0:
			raise PhidgetException(result)


	def getMinAcceleration(self):
		_MinAcceleration = ctypes.c_double()
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

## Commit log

2020-06-24 v3.2
    Design files
    [baffle_filterCube_bottom.stl, baffle_filterCube_spacer.stl, baffle_filterCube_top.stl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]
2022-06-14 Add files via upload
    List of parts and components
    [BAFFLEdoc_parts.xlsx]
